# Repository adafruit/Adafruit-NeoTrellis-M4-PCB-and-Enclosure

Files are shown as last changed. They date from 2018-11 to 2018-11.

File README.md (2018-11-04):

# Adafruit-NeoTrellis-M4-PCB-and-Enclosure
CAD files for the Adafruit NeoTrellis M4 PCB and Enclosure

PCB format is EagleCAD schematic and board layout
Enclosure format is Illustrator, cut from 3mm Acrylic

For more details, check out the product pages at

   * https://www.adafruit.com/product/4020
   * https://www.adafruit.com/product/3938
   * https://www.adafruit.com/product/3963

Adafruit invests time and resources providing this open source design, 
please support Adafruit and open-source hardware by purchasing 
products from Adafruit!

Designed by Adafruit Industries.  
Creative Commons Attribution, Share-Alike license, check license.txt for more information
All text above must be included in any redistribution

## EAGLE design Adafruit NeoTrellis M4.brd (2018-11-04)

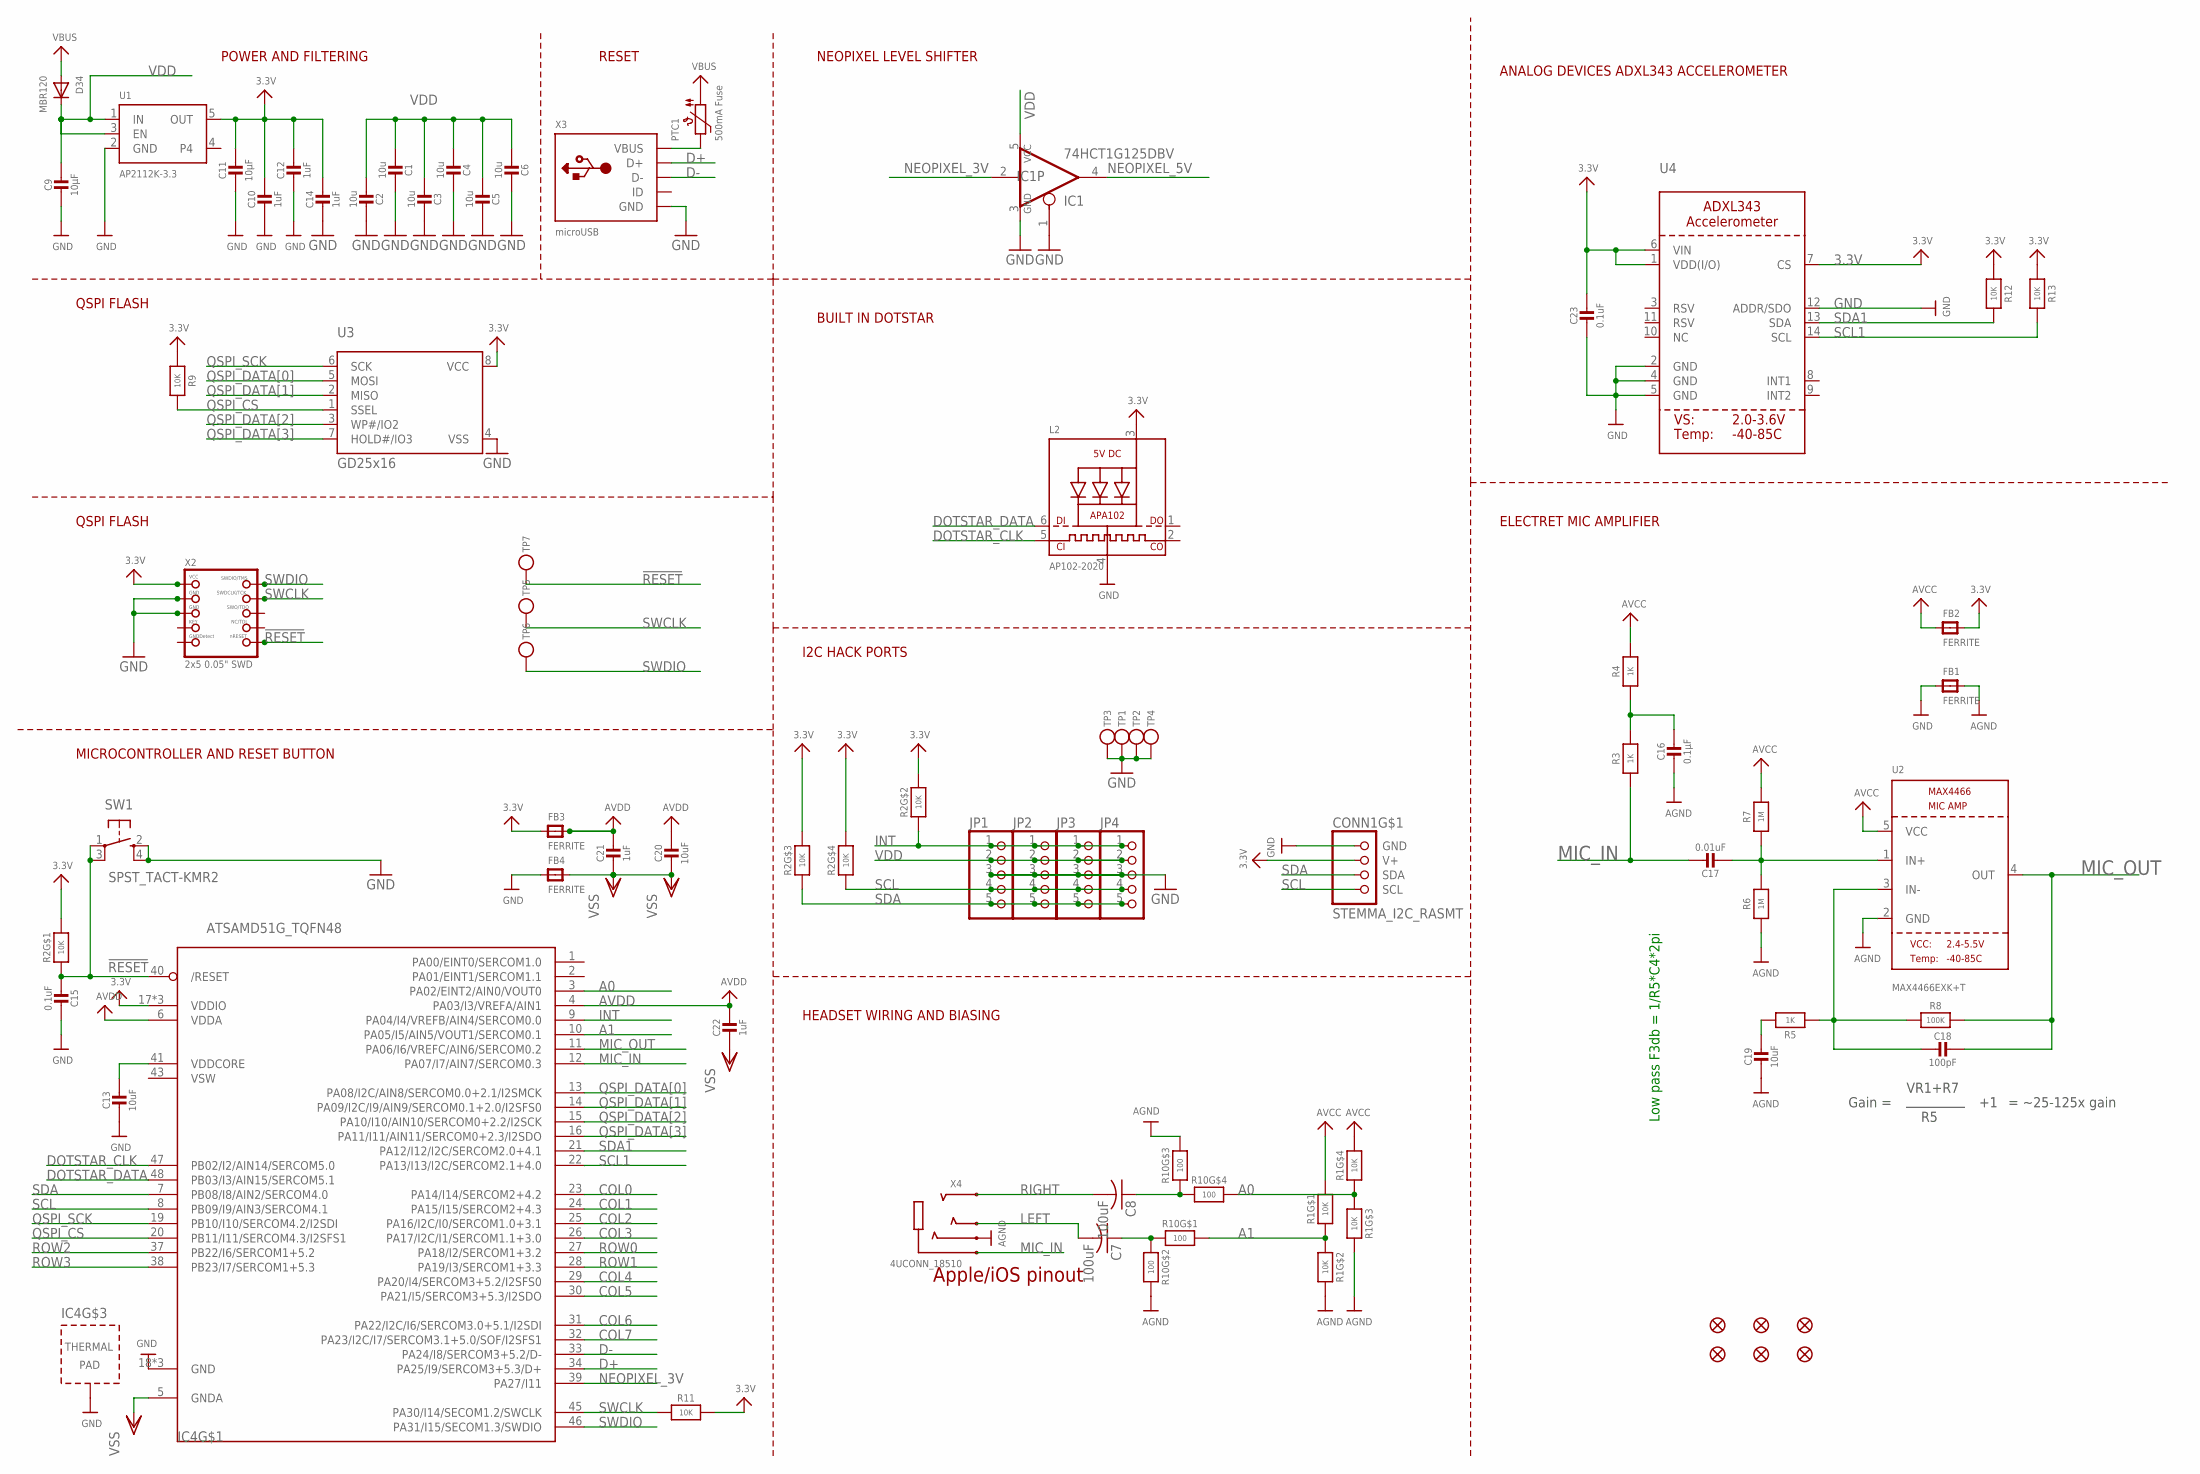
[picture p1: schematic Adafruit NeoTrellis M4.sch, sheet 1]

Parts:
C1, C2, C3, C4, C5, C6: 10u; 0805-NO
C7, C8: 100uF; C1210
C9, C11: 10µF; 0805-NO
C10, C12, C14, C21, C22: 1uF; 0603-NO
C13, C19, C20: 10uF; 0805-NO
C15, C23: 0.1uF; 0603-NO
C16: 0.1µF; 0603-NO
C17: 0.01uF; 0603-NO
C18: 100pF; 0603-NO
CONN1: STEMMA_I2C_RASMT; JSTPH4
D34: MBR120; SOD-123FL
FB1, FB2: FERRITE; 0805
FB3, FB4: FERRITE; 0805-NO
FID1, FID2, FID3, FID4, FID5, FID6: FIDUCIAL_1MM
IC1: 74HCT1G125DBV; SOT23-5
IC4: ATSAMD51G_TQFN48; TQFN48_7MM
JP1, JP2, JP3, JP4: HEADER-1X5EDGESMT; 5P_EDGECONNECT
L2: AP102-2020; APA102_2020
PTC1: 500mA Fuse; 1206
R1, R2: 10K; RESPACK_4X0603
R3, R4, R5: 1K; 0603-NO
R6, R7: 1M; 0603-NO
R8: 100K; 0603-NO
R9, R11, R12, R13: 10K; 0603-NO
R10: 100; RESPACK_4X0603
SW1: SPST_TACT-KMR2; KMR2
TP1, TP2, TP3, TP4: TESTPOINT; TESTPOINT_SMT
TP5, TP6: TESTPOINTROUND2MM; TESTPOINT_ROUND_2MM
TP7: TESTPOINTROUND1.5MM; TESTPOINT_ROUND_1.5MM
U1: AP2112K-3.3; SOT23-5
U2: MAX4466EXK+T; SC70-5
U3: GD25x16; SOIC8_208MIL
U4: ACCEL_ADXL343; LGA14
X2: 2x5 0.05" SWD; 2X05_1.27MM_BOX_POSTS
X3: microUSB; 4UCONN_20329_NARROW
X4: 4UCONN_18510

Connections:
3.3V: C10.1, C11.1, C12.1, C14.1, C23.1, CONN1.2 (V+), FB2.2, FB3.1, IC4.17 (VDDIO), IC4.36 (VDDIO), IC4.44 (VDDIO), L2.3 (VDD), R2.5 (2), R2.6 (2), R2.7 (2), R2.8 (2), R9.1, R11.2, R12.1, R13.1, U1.5 (OUT), U3.8 (VCC), U4.1 (VDD(I/O)), U4.6 (VIN), U4.7 (CS), X2.1 (VCC)
!RESET: C15.2, IC4.40 (/RESET), R2.1, SW1.1, SW1.3 (P1), TP7.P$1, X2.10 (NRESET)
A0: IC4.3 (PA02/EINT2/AIN0/VOUT0), R1.3 (1), R1.4 (1), R10.5 (2)
A1: IC4.10 (PA05/I5/AIN5/VOUT1/SERCOM0.1), R1.1, R1.2 (1), R10.8 (2)
AGND: C16.2, C19.2, FB1.2, R1.6 (2), R1.7 (2), R6.1, R10.6 (2), R10.7 (2), U2.2 (GND), X4.4-INNER_SLEEVE (RING1)
AVCC: FB2.1, R1.5 (2), R1.8 (2), R4.2, R7.2, U2.5 (VCC)
AVDD: C20.1, C21.1, C22.1, FB3.2, IC4.4 (PA03/I3/VREFA/AIN1), IC4.6 (VDDA)
COL0: IC4.23 (PA14/I14/SERCOM2+4.2); also elsewhere on the board
COL1: IC4.24 (PA15/I15/SERCOM2+4.3); also elsewhere on the board
COL2: IC4.25 (PA16/I2C/I0/SERCOM1.0+3.1); also elsewhere on the board
COL3: IC4.26 (PA17/I2C/I1/SERCOM1.1+3.0); also elsewhere on the board
COL4: IC4.29 (PA20/I4/SERCOM3+5.2/I2SFS0); also elsewhere on the board
COL5: IC4.30 (PA21/I5/SERCOM3+5.3/I2SDO); also elsewhere on the board
COL6: IC4.31 (PA22/I2C/I6/SERCOM3.0+5.1/I2SDI); also elsewhere on the board
COL7: IC4.32 (PA23/I2C/I7/SERCOM3.1+5.0/SOF/I2SFS1); also elsewhere on the board
D+: IC4.34 (PA25/I9/SERCOM3+5.3/D+), X3.D+
D-: IC4.33 (PA24/I8/SERCOM3+5.2/D-), X3.D-
DOTSTAR_CLK: IC4.47 (PB02/I2/AIN14/SERCOM5.0), L2.5 (CKI)
DOTSTAR_DATA: IC4.48 (PB03/I3/AIN15/SERCOM5.1), L2.6 (DI)
GND: C1.1, C2.1, C3.1, C4.1, C5.1, C6.1, C9.2, C10.2, C11.2, C12.2, C13.2, C14.2, C15.1, C23.2, CONN1.1 (GND), FB1.1, FB4.1, IC1.1 (OE), IC1.3 (GND), IC4.18 (GND), IC4.35 (GND), IC4.42 (GND), IC4.THERMAL (TP), JP1.3, JP2.3, JP3.3, JP4.3, L2.4 (GND), SW1.2 (S), SW1.4 (S1), TP1.P$1, TP2.P$1, TP3.P$1, TP4.P$1, U1.2 (GND), U3.4 (VSS), U4.2 (GND), U4.4 (GND), U4.5 (GND), U4.12 (ADDR/SDO), X2.3 (GND), X2.5 (GND), X3.BASE@1 (GND), X3.BASE@2 (GND), X3.GND, X3.SPRT@1 (GND), X3.SPRT@2 (GND), X3.SPRT@3 (GND), X3.SPRT@4 (GND); also elsewhere on the board
INT: IC4.9 (PA04/I4/VREFB/AIN4/SERCOM0.0), JP1.1, JP2.1, JP3.1, JP4.1, R2.2 (1)
LEFT: C7.2, X4.2-TIP (RING3)
MIC_IN: C17.1, IC4.12 (PA07/I7/AIN7/SERCOM0.3), R3.1, X4.1-GND (TIP)
MIC_OUT: C18.1, IC4.11 (PA06/I6/VREFC/AIN6/SERCOM0.2), R8.2, U2.4 (OUT)
unnamed: C8.1, R10.3 (1), R10.4 (1)
unnamed: C16.1, R3.2, R4.1
unnamed: PTC1.2, X3.VBUS
unnamed: C17.2, R6.2, R7.1, U2.1 (IN+)
unnamed: C18.2, R5.1, R8.1, U2.3 (IN-)
unnamed: C19.1, R5.2
unnamed: C7.1, R10.1, R10.2 (1)
NEOPIXEL_3V: IC1.2 (I), IC4.39 (PA27/I11)
NEOPIXEL_5V: IC1.4 (O); also elsewhere on the board
QSPI_CS: IC4.20 (PB11/I11/SERCOM4.3/I2SFS1), R9.2, U3.1 (SSEL)
QSPI_DATA[0]: IC4.13 (PA08/I2C/AIN8/SERCOM0.0+2.1/I2SMCK), U3.5 (MOSI)
QSPI_DATA[1]: IC4.14 (PA09/I2C/I9/AIN9/SERCOM0.1+2.0/I2SFS0), U3.2 (MISO)
QSPI_DATA[2]: IC4.15 (PA10/I10/AIN10/SERCOM0+2.2/I2SCK), U3.3 (WP#/IO2)
QSPI_DATA[3]: IC4.16 (PA11/I11/AIN11/SERCOM0+2.3/I2SDO), U3.7 (HOLD#/IO3)
QSPI_SCK: IC4.19 (PB10/I10/SERCOM4.2/I2SDI), U3.6 (SCK)
RIGHT: C8.2, X4.3-OUTER_SLEEVE (RING2)
ROW0: IC4.27 (PA18/I2/SERCOM1+3.2); also elsewhere on the board
ROW1: IC4.28 (PA19/I3/SERCOM1+3.3); also elsewhere on the board
ROW2: IC4.37 (PB22/I6/SERCOM1+5.2); also elsewhere on the board
ROW3: IC4.38 (PB23/I7/SERCOM1+5.3); also elsewhere on the board
SCL: CONN1.4 (SCL), IC4.8 (PB09/I9/AIN3/SERCOM4.1), JP1.4, JP2.4, JP3.4, JP4.4, R2.4 (1)
SCL1: IC4.22 (PA13/I13/I2C/SERCOM2.1+4.0), R13.2, U4.14 (SCL)
SDA: CONN1.3 (SDA), IC4.7 (PB08/I8/AIN2/SERCOM4.0), JP1.5, JP2.5, JP3.5, JP4.5, R2.3 (1)
SDA1: IC4.21 (PA12/I12/I2C/SERCOM2.0+4.1), R12.2, U4.13 (SDA)
SWCLK: IC4.45 (PA30/I14/SECOM1.2/SWCLK), R11.1, TP5.P$1, X2.4 (SWDCLK)
SWDIO: IC4.46 (PA31/I15/SECOM1.3/SWDIO), TP6.P$1, X2.2 (SWDIO)
VBUS: D34.A, PTC1.1
VDD: C1.2, C2.2, C3.2, C4.2, C5.2, C6.2, C9.1, D34.C, IC1.5 (VCC), JP1.2, JP2.2, JP3.2, JP4.2, U1.1 (IN), U1.3 (EN); also elsewhere on the board
VDDCORE: C13.1, IC4.41 (VDDCORE)
VSS: C20.2, C21.2, C22.2, FB4.2, IC4.5 (GNDA)
VSW: IC4.43 (VSW)

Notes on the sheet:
POWER AND FILTERING
RESET
Apple/iOS pinout
Gain =
VR1+R7
= ~25-125x gain
Low pass F3db = 1/R5*C4*2pi
NEOPIXEL LEVEL SHIFTER
BUILT IN DOTSTAR
I2C HACK PORTS
HEADSET WIRING AND BIASING
QSPI FLASH
MICROCONTROLLER AND RESET BUTTON
ELECTRET MIC AMPLIFIER
ANALOG DEVICES ADXL343 ACCELEROMETER

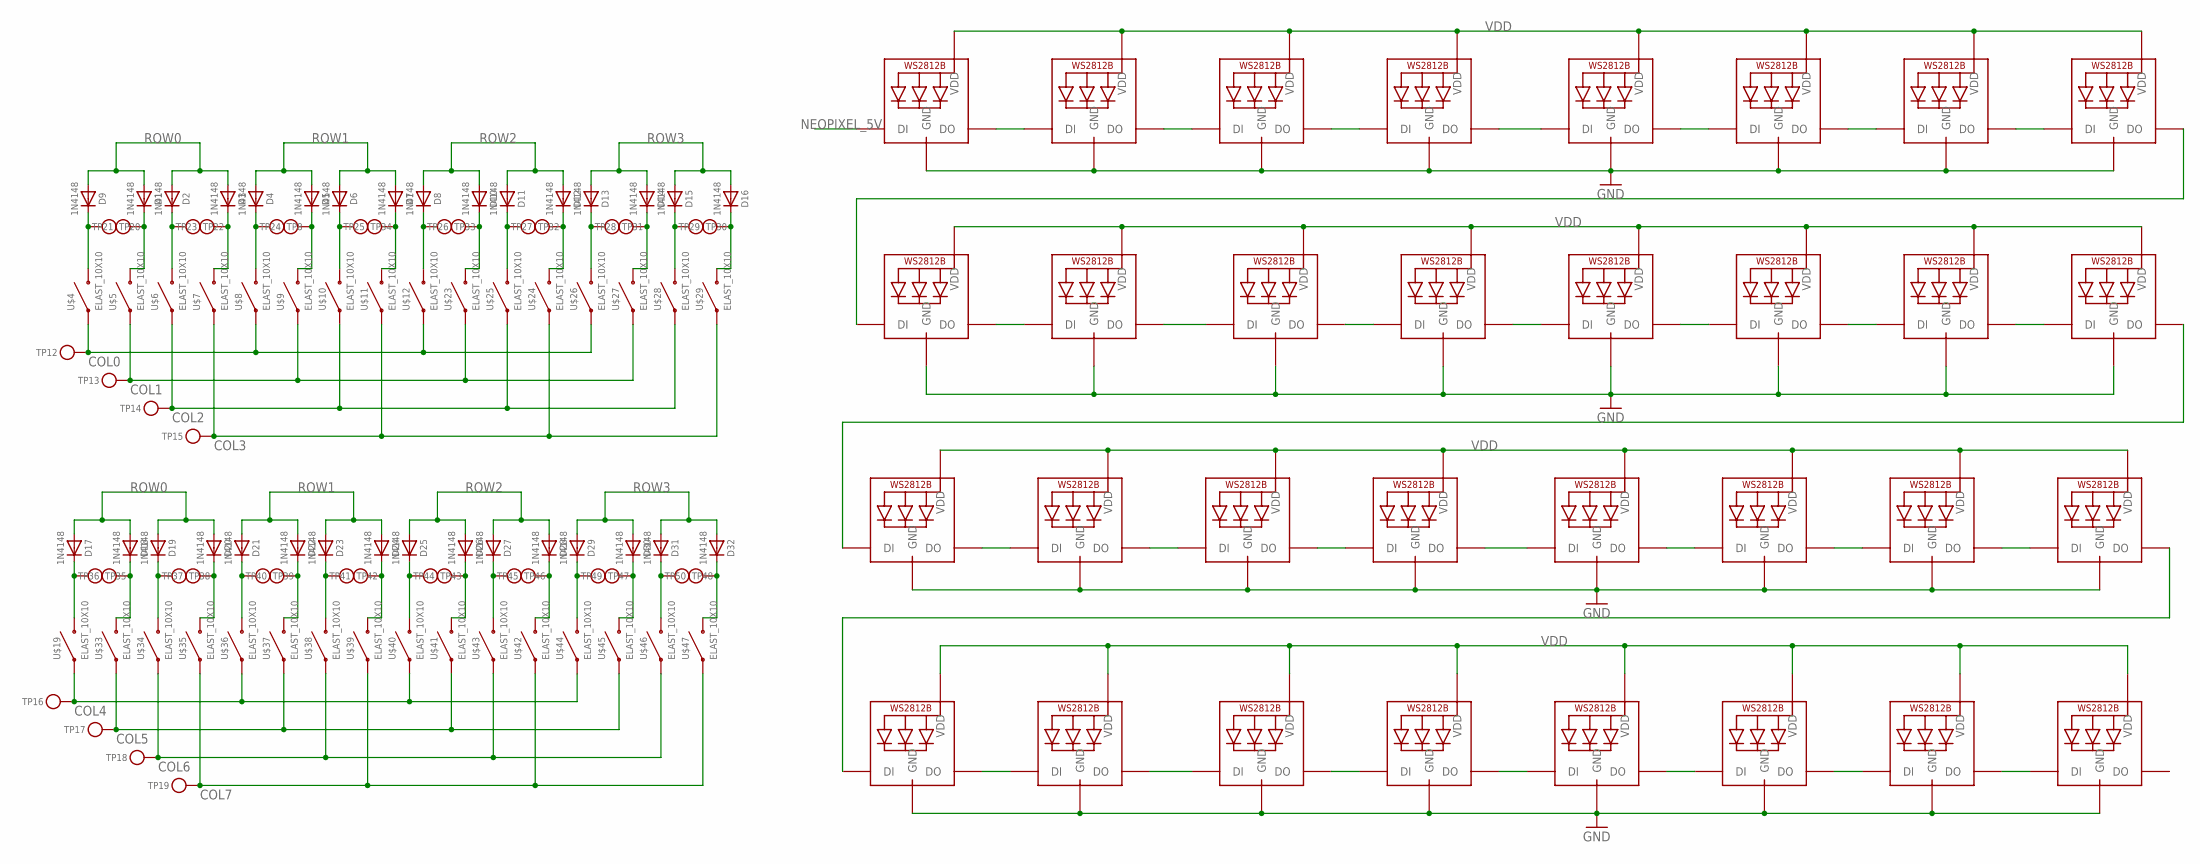
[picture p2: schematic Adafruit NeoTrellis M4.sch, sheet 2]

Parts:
D1, D2, D3, D4, D5, D6, D7, D8, D9, D10, D11, D12, D13, D14, D15, D16, D17, D18, D19, D20, D21, D22, D23, D24, D25, D26, D27, D28, D29, D30, D31, D32: 1N4148; SOD-323
LED1, LED2, LED3, LED4, LED5, LED6, LED7, LED8, LED9, LED10, LED11, LED12, LED13, LED14, LED15, LED16, LED17, LED18, LED19, LED20, LED21, LED22, LED23, LED24, LED25, LED26, LED27, LED28, LED29, LED30, LED31, LED32: WS2812B3535; LED3535
TP8, TP12, TP13, TP14, TP15, TP16, TP17, TP18, TP19, TP20, TP21, TP22, TP23, TP24, TP25, TP26, TP27, TP28, TP29, TP30, TP31, TP32, TP33, TP34, TP35, TP36, TP37, TP38, TP39, TP40, TP41, TP42, TP43, TP44, TP45, TP46, TP47, TP48, TP49, TP50: TESTPOINTROUND1.5MM; TESTPOINT_ROUND_1.5MM
U$4, U$5, U$6, U$7, U$8, U$9, U$10, U$11, U$12, U$19, U$23, U$24, U$25, U$26, U$27, U$28, U$29, U$33, U$34, U$35, U$36, U$37, U$38, U$39, U$40, U$41, U$42, U$43, U$44, U$45, U$46, U$47: ELAST_10X10; ELAST_PAD_SQUARE_10MM_4X4WIDE

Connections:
COL0: TP12.P$1, U$4.P$1, U$8.P$1, U$12.P$1, U$26.P$1; also elsewhere on the board
COL1: TP13.P$1, U$5.P$1, U$9.P$1, U$23.P$1, U$27.P$1; also elsewhere on the board
COL2: TP14.P$1, U$6.P$1, U$10.P$1, U$25.P$1, U$28.P$1; also elsewhere on the board
COL3: TP15.P$1, U$7.P$1, U$11.P$1, U$24.P$1, U$29.P$1; also elsewhere on the board
COL4: TP16.P$1, U$19.P$1, U$36.P$1, U$40.P$1, U$44.P$1; also elsewhere on the board
COL5: TP17.P$1, U$33.P$1, U$37.P$1, U$41.P$1, U$45.P$1; also elsewhere on the board
COL6: TP18.P$1, U$34.P$1, U$38.P$1, U$43.P$1, U$46.P$1; also elsewhere on the board
COL7: TP19.P$1, U$35.P$1, U$39.P$1, U$42.P$1, U$47.P$1; also elsewhere on the board
GND: LED1.4 (GND), LED2.4 (GND), LED3.4 (GND), LED4.4 (GND), LED5.4 (GND), LED6.4 (GND), LED7.4 (GND), LED8.4 (GND), LED9.4 (GND), LED10.4 (GND), LED11.4 (GND), LED12.4 (GND), LED13.4 (GND), LED14.4 (GND), LED15.4 (GND), LED16.4 (GND), LED17.4 (GND), LED18.4 (GND), LED19.4 (GND), LED20.4 (GND), LED21.4 (GND), LED22.4 (GND), LED23.4 (GND), LED24.4 (GND), LED25.4 (GND), LED26.4 (GND), LED27.4 (GND), LED28.4 (GND), LED29.4 (GND), LED30.4 (GND), LED31.4 (GND), LED32.4 (GND); also elsewhere on the board
unnamed: D9.C, TP20.P$1, U$4.P$2
unnamed: D1.C, TP21.P$1, U$5.P$2
unnamed: D2.C, TP22.P$1, U$6.P$2
unnamed: D3.C, TP23.P$1, U$7.P$2
unnamed: D4.C, TP8.P$1, U$8.P$2
unnamed: LED17.3 (DO), LED18.1 (DI)
unnamed: LED18.3 (DO), LED19.1 (DI)
unnamed: D5.C, TP24.P$1, U$9.P$2
unnamed: LED19.3 (DO), LED20.1 (DI)
unnamed: LED1.3 (DO), LED2.1 (DI)
unnamed: LED2.3 (DO), LED3.1 (DI)
unnamed: LED3.3 (DO), LED4.1 (DI)
unnamed: LED4.3 (DO), LED5.1 (DI)
unnamed: D6.C, TP34.P$1, U$10.P$2
unnamed: LED5.3 (DO), LED6.1 (DI)
unnamed: LED6.3 (DO), LED7.1 (DI)
unnamed: D7.C, TP25.P$1, U$11.P$2
unnamed: LED7.3 (DO), LED8.1 (DI)
unnamed: D8.C, TP33.P$1, U$12.P$2
unnamed: LED8.3 (DO), LED9.1 (DI)
unnamed: D10.C, TP26.P$1, U$23.P$2
unnamed: D11.C, TP32.P$1, U$25.P$2
unnamed: D12.C, TP27.P$1, U$24.P$2
unnamed: D13.C, TP31.P$1, U$26.P$2
unnamed: D14.C, TP28.P$1, U$27.P$2
unnamed: D15.C, TP30.P$1, U$28.P$2
unnamed: D16.C, TP29.P$1, U$29.P$2
unnamed: LED9.3 (DO), LED10.1 (DI)
unnamed: LED10.3 (DO), LED12.1 (DI)
unnamed: LED11.1 (DI), LED12.3 (DO)
unnamed: LED11.3 (DO), LED13.1 (DI)
unnamed: LED13.3 (DO), LED14.1 (DI)
unnamed: LED14.3 (DO), LED15.1 (DI)
unnamed: LED15.3 (DO), LED16.1 (DI)
unnamed: LED20.3 (DO), LED21.1 (DI)
unnamed: LED21.3 (DO), LED22.1 (DI)
unnamed: LED22.3 (DO), LED23.1 (DI)
unnamed: LED23.3 (DO), LED24.1 (DI)
unnamed: LED24.3 (DO), LED25.1 (DI)
unnamed: LED25.3 (DO), LED26.1 (DI)
unnamed: LED26.3 (DO), LED28.1 (DI)
unnamed: LED27.1 (DI), LED28.3 (DO)
unnamed: LED27.3 (DO), LED29.1 (DI)
unnamed: LED29.3 (DO), LED30.1 (DI)
unnamed: LED30.3 (DO), LED31.1 (DI)
unnamed: LED31.3 (DO), LED32.1 (DI)
unnamed: D17.C, TP35.P$1, U$19.P$2
unnamed: D18.C, TP36.P$1, U$33.P$2
unnamed: D19.C, TP38.P$1, U$34.P$2
unnamed: D20.C, TP37.P$1, U$35.P$2
unnamed: D21.C, TP39.P$1, U$36.P$2
unnamed: D22.C, TP40.P$1, U$37.P$2
unnamed: D23.C, TP42.P$1, U$38.P$2
unnamed: D24.C, TP41.P$1, U$39.P$2
unnamed: D25.C, TP43.P$1, U$40.P$2
unnamed: D26.C, TP44.P$1, U$41.P$2
unnamed: D27.C, TP46.P$1, U$43.P$2
unnamed: D28.C, TP45.P$1, U$42.P$2
unnamed: D29.C, TP47.P$1, U$44.P$2
unnamed: D30.C, TP49.P$1, U$45.P$2
unnamed: D31.C, TP48.P$1, U$46.P$2
unnamed: D32.C, TP50.P$1, U$47.P$2
unnamed: LED16.3 (DO), LED17.1 (DI)
NEOPIXEL_5V: LED1.1 (DI); also elsewhere on the board
ROW0: D1.A, D2.A, D3.A, D9.A, D17.A, D18.A, D19.A, D20.A; also elsewhere on the board
ROW1: D4.A, D5.A, D6.A, D7.A, D21.A, D22.A, D23.A, D24.A; also elsewhere on the board
ROW2: D8.A, D10.A, D11.A, D12.A, D25.A, D26.A, D27.A, D28.A; also elsewhere on the board
ROW3: D13.A, D14.A, D15.A, D16.A, D29.A, D30.A, D31.A, D32.A; also elsewhere on the board
VDD: LED1.2 (VDD), LED2.2 (VDD), LED3.2 (VDD), LED4.2 (VDD), LED5.2 (VDD), LED6.2 (VDD), LED7.2 (VDD), LED8.2 (VDD), LED9.2 (VDD), LED10.2 (VDD), LED11.2 (VDD), LED12.2 (VDD), LED13.2 (VDD), LED14.2 (VDD), LED15.2 (VDD), LED16.2 (VDD), LED17.2 (VDD), LED18.2 (VDD), LED19.2 (VDD), LED20.2 (VDD), LED21.2 (VDD), LED22.2 (VDD), LED23.2 (VDD), LED24.2 (VDD), LED25.2 (VDD), LED26.2 (VDD), LED27.2 (VDD), LED28.2 (VDD), LED29.2 (VDD), LED30.2 (VDD), LED31.2 (VDD), LED32.2 (VDD); also elsewhere on the board

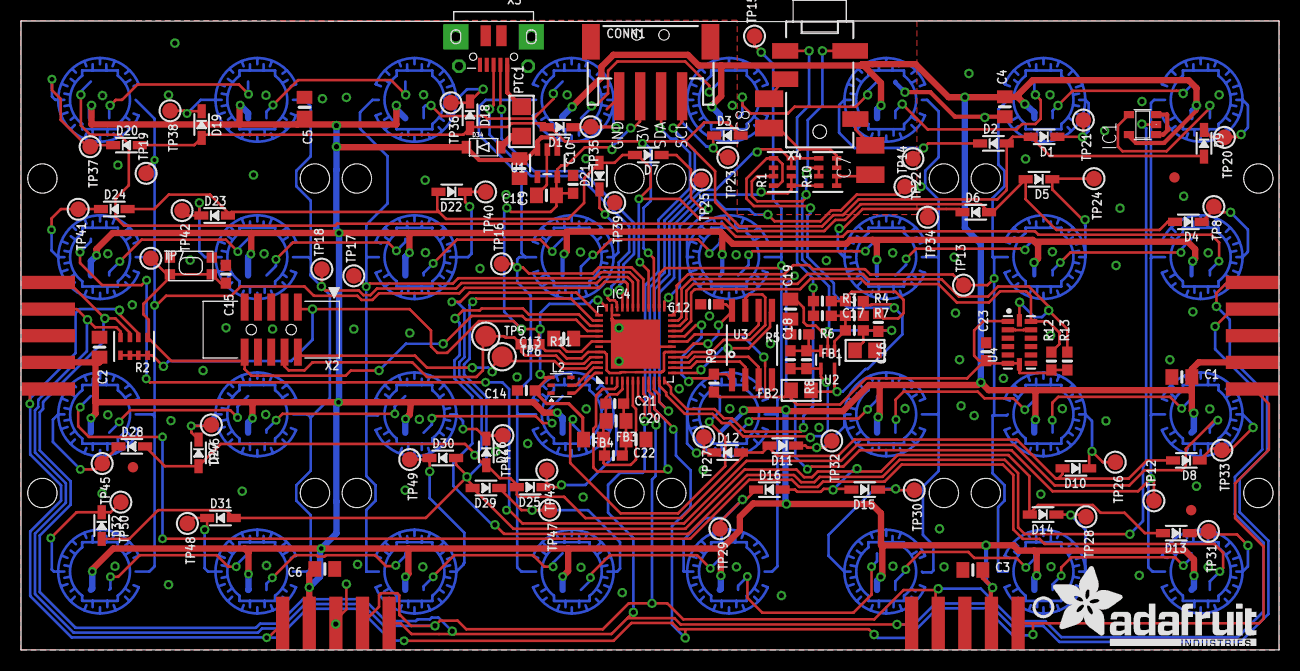
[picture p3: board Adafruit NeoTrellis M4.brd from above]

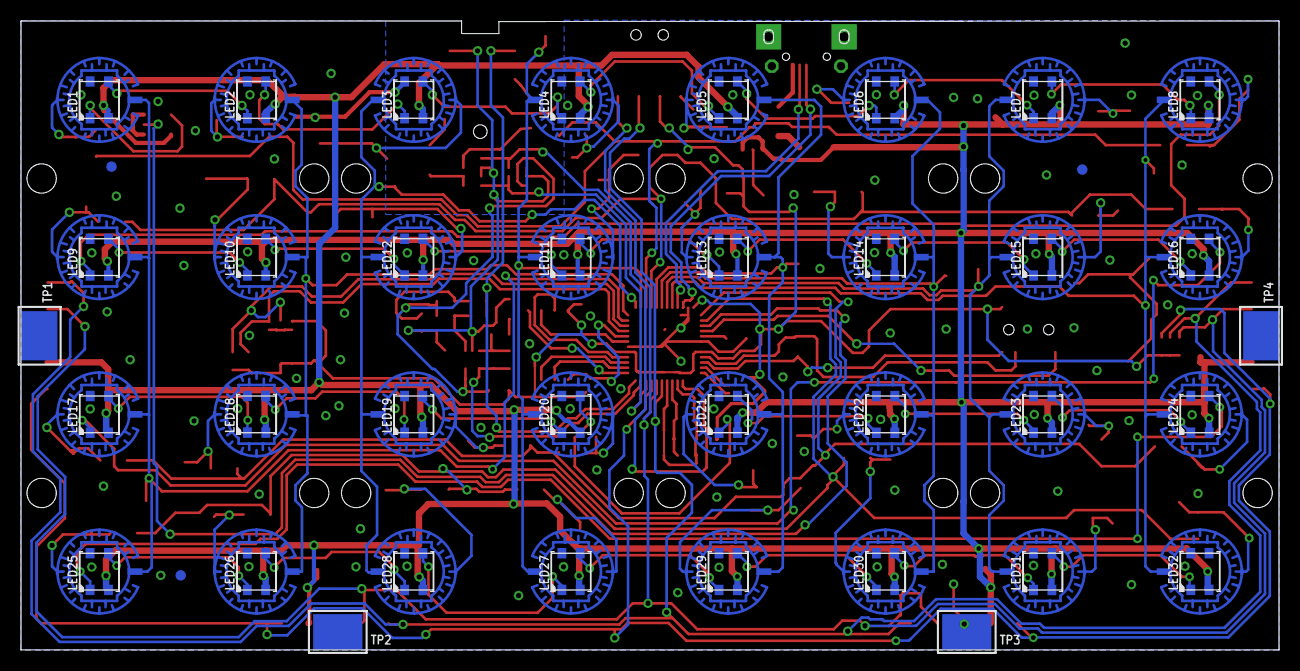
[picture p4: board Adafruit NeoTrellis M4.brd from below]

Board: 2 copper layers, 120.0 x 60.0 mm, 210 parts (71 on the bottom side), 117 nets.

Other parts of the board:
U$3: ADAFRUIT_TEXT_20MM
U$48: TRELLISLOGO
U$78: PCBFEAT-REV-040

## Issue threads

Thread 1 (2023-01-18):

random keypresses when holding third button down on the left side.

tigerteeth, 2023-01-18:
hi, I'm using the neotrellis m4 as a macropad, sending key presses via USB. The code I am using is from adapted from this page https://learn.adafruit.com/launch-deck-trellis-m4/code-with-circuitpython

When I hold the third button down on the left (and especially if i give it a wiggle) the device sends random keypresses (always keys from the third row of the device). Is there a problem with my board? The problem is reproducible and consistent.

I updated everything (as of 18 jan 2023) and followed all the instructions to get the device running properly.

TheKitty, 2023-01-18:
Please post your query to https://learn..adafruit.com for product support.

tigerteeth, 2023-01-18:
what's that url?

TheKitty, 2023-01-19:
https://forums.adafruit.com

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

Closed 2023-01-18.

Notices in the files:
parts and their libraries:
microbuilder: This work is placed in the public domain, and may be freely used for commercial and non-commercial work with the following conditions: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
